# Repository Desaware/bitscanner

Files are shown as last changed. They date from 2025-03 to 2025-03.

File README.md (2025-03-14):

# Bitscanner - A LittleBits/Arduino Compatible Scope/Frequency Counter and Voltmeter - Software

Refer to https://github.com/Desaware/bitscanner/wiki for documentation.

## Software Requirements

Bitscanner is built on the Raspberry Pi Pico 1 (RP2040), using the Pico SDK under Visual Studio Code.

It also uses the pico-ssd1306 library found at https://github.com/daschr/pico-ssd1306, portions of which are included in this repository.

To build, copy the files in this directory to the root of a Raspberry Pi Pico project in VS Code. Be sure to include the CMakeList.txt file. You should then be able to compile and upload the project to your pico device when it is in bootloader mode.

Refer to your Pico documentation or friendly neighborhood AI for instructions on setting up VS Code with the Pico SDK and building and deploying software in that environment.

Disclaimer: This product is not affiliated with, endorsed by, or sponsored by Sphero, Inc. "littleBits" is a registered trademark of Sphero, Inc. All trademarks, product names, and company names or logos mentioned herein are the property of their respective owners. This device is designed to be compatible with littleBits components but is an independent creation with no official connection to Sphero, Inc.

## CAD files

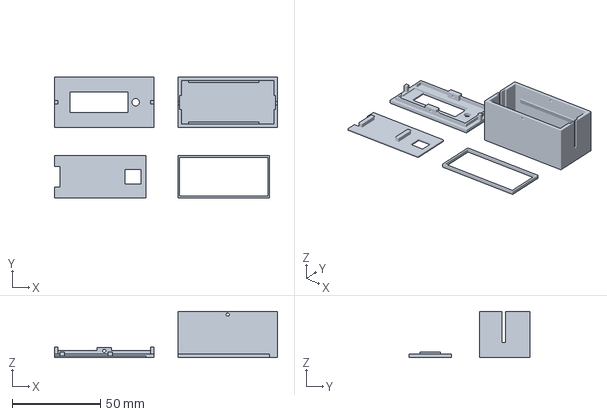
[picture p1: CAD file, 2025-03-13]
Case/sannercase.3mf
126.5 x 68.5 x 26.3 mm

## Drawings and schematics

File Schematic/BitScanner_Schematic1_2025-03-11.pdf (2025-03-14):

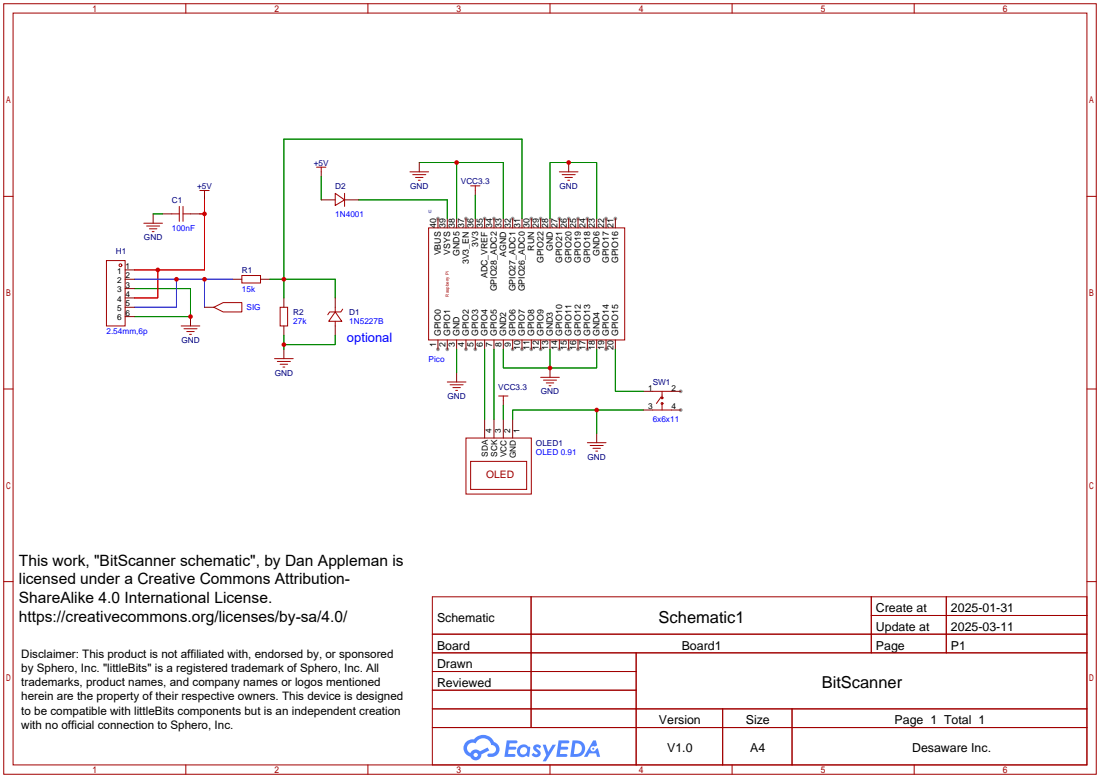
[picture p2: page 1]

This work, "BitScanner schematic", by Dan Appleman is
licensed under a Creative Commons Attribution-
ShareAlike 4.0 International License.
https://creativecommons.org/licenses/by-sa/4.0/

Schematic | Schematic1 | Create at | 2025-01-31

Update at | 2025-03-11

Board | Board1 | Page | P1
Drawn | | BitScanner
Reviewed

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

Version | Size | Page 1 Total 1
V1.0 | A4 | Desaware Inc.

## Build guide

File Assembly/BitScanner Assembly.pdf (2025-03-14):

# BitScanner Assembly

These are instructions for assembling the BitScanner using the PCB and case design provided in this repository. Obviously, you can create your own variations, in which case, just as obviously, these assembly instructions will not apply.
This document is Copyright © 2025 by Dan Appleman.
Disclaimer: This product is not affiliated with, endorsed by, or sponsored by Sphero, Inc. "LittleBits" is a trademark of Sphero, Inc. All trademarks, product names, and company names or logos mentioned herein are the property of their respective owners. This device is designed to be compatible with LittleBits components but is an independent creation with no official connection to Sphero, Inc.

## Overview

The BitScanner consists of one printed circuit board with components mounted on the top and bottom. The bottom contains the I/O connector resistors, diode and capacitor, along with 20 pin header sockets for the Raspberry Pi Pico. The pico plugs in and sits below the components (the socket, at 7mm, being tall enough to provide space for the components between the PCB and the Pico.
On the top of the PCB you have the OLED display and the push button. A spacer and display mount hold the OLED above the PCB, leaving space for the soldered connections and holding the OLED at the the correct height. A rectangular opening provides space for the button.

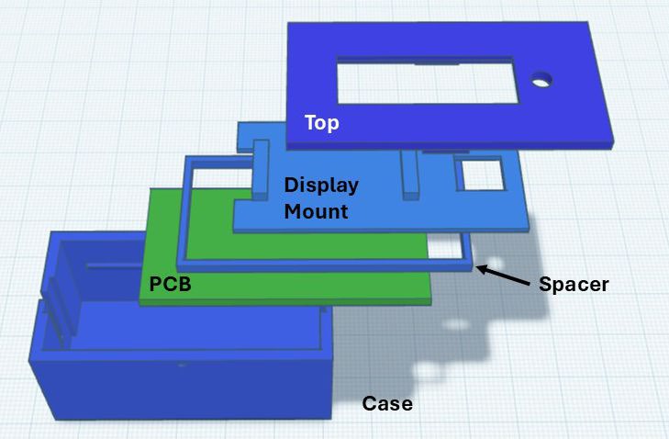
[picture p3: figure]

## PCB Bottom

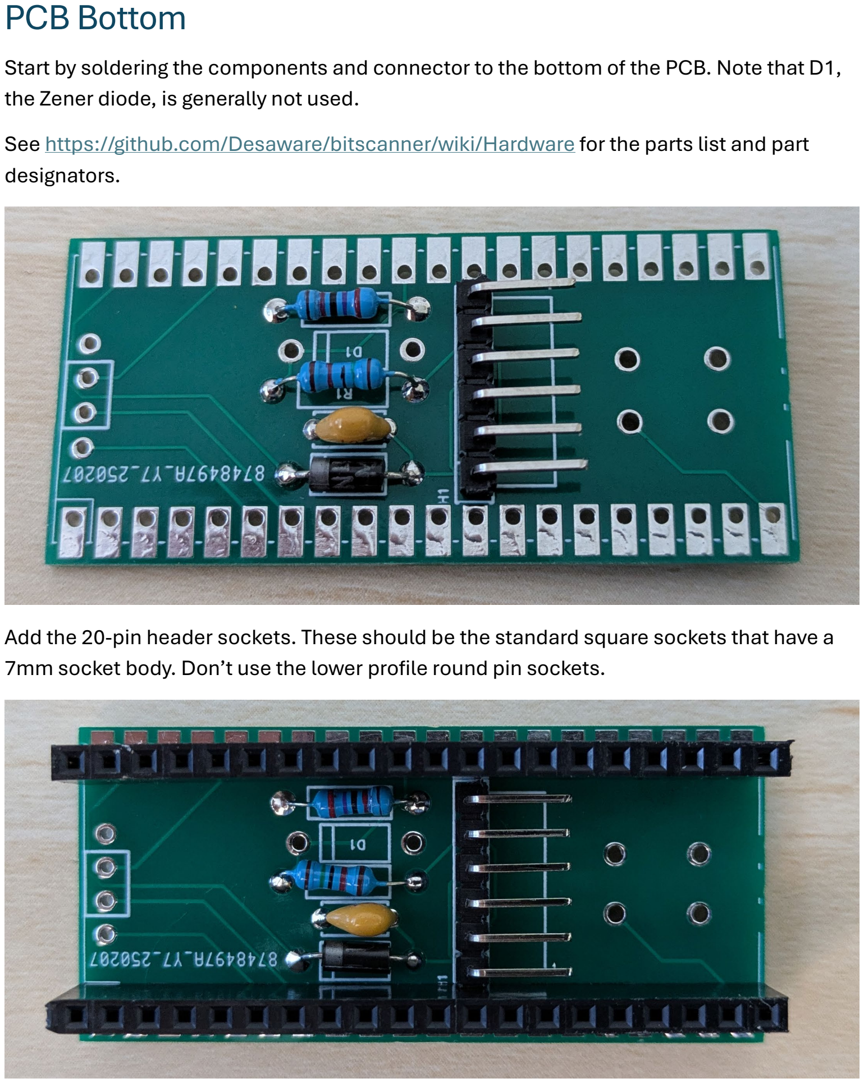
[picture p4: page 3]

Start by soldering the components and connector to the bottom of the PCB. Note that D1, the Zener diode, is generally not used.
See https://github.com/Desaware/bitscanner/wiki/Hardware for the parts list and part designators.

Add the 20-pin header sockets. These should be the standard square sockets that have a 7mm socket body. Don’t use the lower profile round pin sockets.

## PCB Top

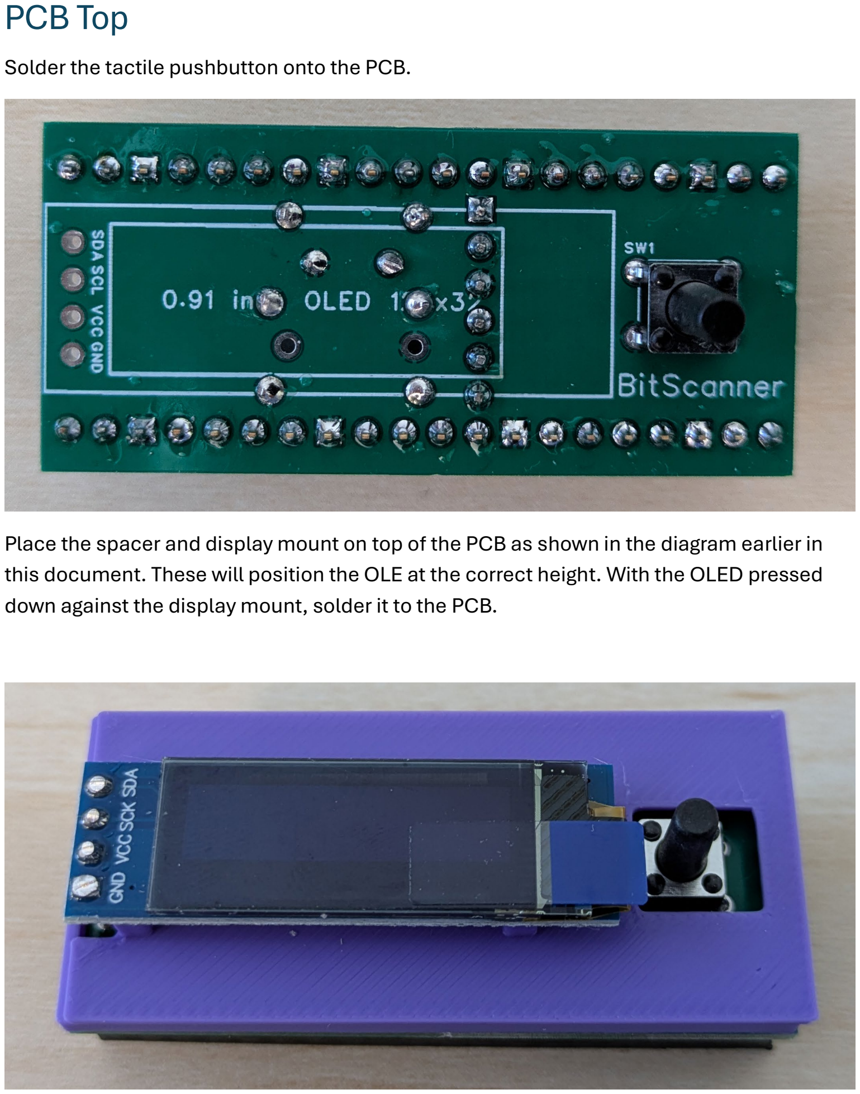
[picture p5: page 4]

Solder the tactile pushbutton onto the PCB.

Place the spacer and display mount on top of the PCB as shown in the diagram earlier in this document. These will position the OLE at the correct height. With the OLED pressed down against the display mount, solder it to the PCB.

## Wires

Connect two JST-SH wire assemblies to a 6-pin connector. On this image, pin 1 is the bottom pin on the connector.
Note the color reversal – on pins 1-3, red is +5 and ground is yellow. On pins 4-6, yellow is +5V and red is ground. This is because of the way the littleBits connectors work (+5V is always the top pin for inputs and outputs).
Plug your wire assemblies into the connectors of a littleBits W1 Wire bit. Be sure to plug the correct connector into the correct wire assembly as shown below!

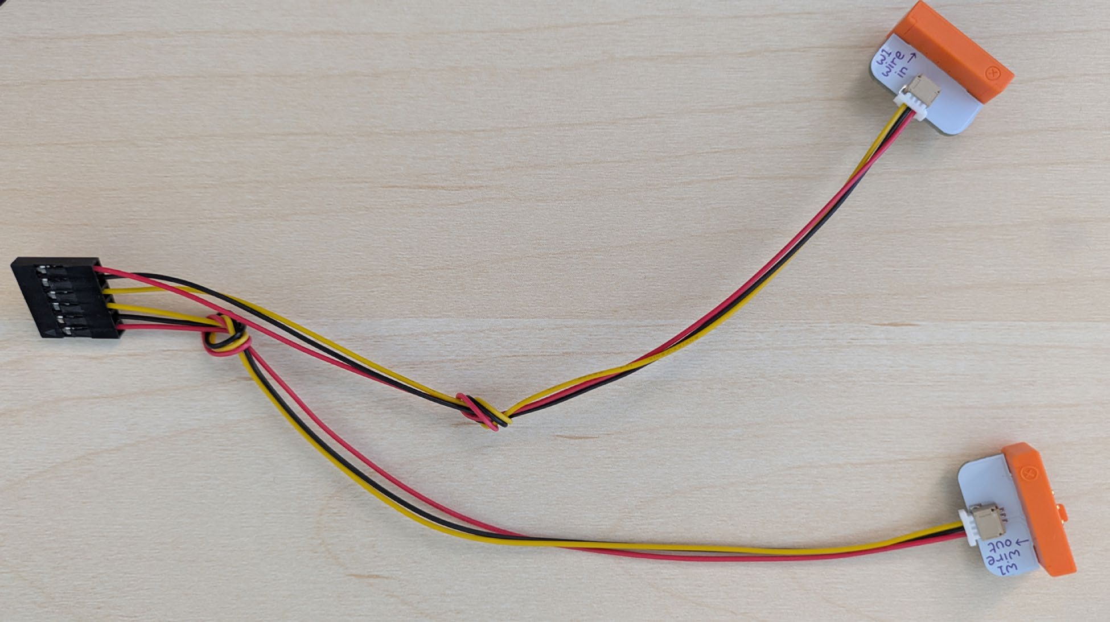
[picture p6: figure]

Tie knots in each wire as shown to act as strain reliefs.

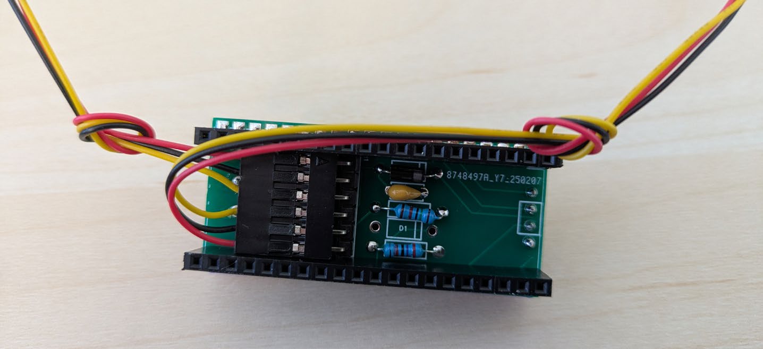
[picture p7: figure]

## Final Assembly

Plug the Raspberry Pi Pico into the header socket (be sure to program it first).
Slide the PCB assembly into the case, placing the wires in the slots. The PCB will sit on the PCB mounts in the case.
Place the case top on the case.
There are two holes on the side for #2 x ¼ self-tapping screws.

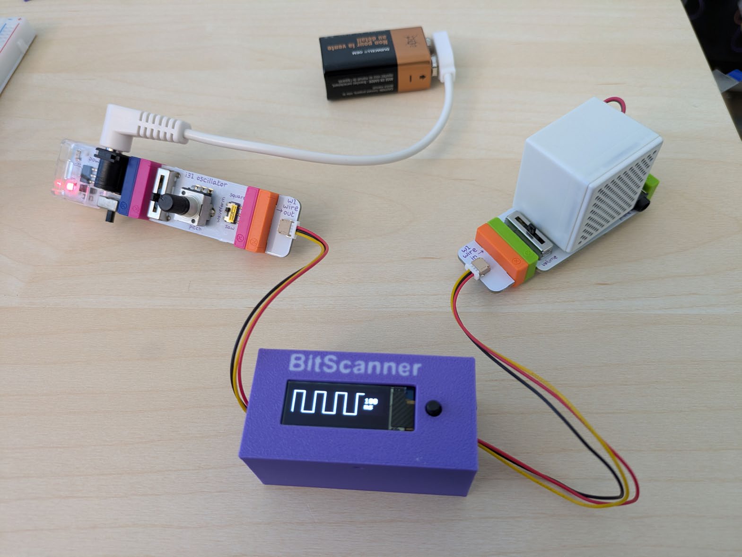
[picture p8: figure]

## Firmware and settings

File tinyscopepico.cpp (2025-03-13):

/*
    Bitscanner - a LittleBits compatible combination oscilloscope, voltmeter and frequency counter
    Copyright (C) 2025 by Dan Appleman

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
    You should have received a copy of the GNU General Public License
    along with this program.  If not, see <https://www.gnu.org/licenses/>.
*/ 

#include <stdio.h>
#include "pico/stdlib.h"
#include "hardware/i2c.h"
#include "hardware/timer.h"
#include "hardware/watchdog.h"
#include "Scope.h"

extern "C"
{
    #include "ssd1306.h"
    #include "font.h"
}

const uint LED_PIN = 25;
const uint MODE_PIN = 15;

// I2C defines
// This example will use I2C0 on GPIO8 (SDA) and GPIO9 (SCL) running at 400KHz.
// Pins can be changed, see the GPIO function select table in the datasheet for information on GPIO assignments
#define I2C_PORT i2c0
#define I2C_SDA 4
#define I2C_SCL 5

ssd1306_t disp;

int main()
{
    sleep_ms(10);  // Some setup time
    stdio_init_all();
    gpio_init(LED_PIN);
    gpio_set_dir(LED_PIN, GPIO_OUT);

    // I2C Initialisation. Using it at 400Khz.
    i2c_init(I2C_PORT, 400*1000);
    sleep_ms(10);  // Some setup time
    
    gpio_set_function(I2C_SDA, GPIO_FUNC_I2C);
    gpio_set_function(I2C_SCL, GPIO_FUNC_I2C);
    gpio_pull_up(I2C_SDA);
    gpio_pull_up(I2C_SCL);
    // For more examples of I2C use see https://github.com/raspberrypi/pico-examples/tree/master/i2c

    // Set up the mode switch
    gpio_init(MODE_PIN);
    gpio_set_dir(MODE_PIN, GPIO_IN);
    gpio_pull_up(MODE_PIN);

    // Watchdog example code
    if (watchdog_caused_reboot()) {
        printf("Rebooted by Watchdog!\n");
        // Whatever action you may take if a watchdog caused a reboot
    }
    
    // Enable the watchdog, requiring the watchdog to be updated every 100ms or the chip will reboot
    // second arg is pause on debug which means the watchdog will pause when stepping through code
    watchdog_enable(2000, 1);
    
    Scope activeScope;


 
    disp.external_vcc=false;
    ssd1306_init(&disp, 128, DISPLAYHEIGHT, 0x3C, I2C_PORT);
    ssd1306_poweron(&disp);
    ssd1306_clear(&disp);
    ssd1306_draw_string(&disp, 2, 4, 2, "BitScanner");


    ssd1306_show(&disp);

    uint64_t watchdog_time = time_us_64();
    uint64_t led_time = time_us_64();
    int ledstate = 0;

    bool debouncingMode = false;
    bool stableMode = true;
    bool lastMode = true;
    uint64_t lastModeCheck = time_us_64();



    while (true) {
        activeScope.poll();
        uint64_t current_time = time_us_64();

        /*if(current_time - led_time > 500000)
        {
            ledstate = (ledstate==0)? 1: 0;
            gpio_put(LED_PIN, ledstate);
            led_time = current_time;
            printf("Frequency: %d\n", activeScope.getCurrentFrequency());
            printf("Voltage: %f\n", activeScope.getCurrentVoltage());
        }
        */

        if(current_time - watchdog_time > 1000000)
        {
            // Once/second update the watchdog
            watchdog_update();
            watchdog_time = current_time;
        }

        bool currentMode = gpio_get(MODE_PIN);
        if(!debouncingMode)
        {
            if(currentMode != stableMode) 
            {
                debouncingMode = true;
                lastModeCheck = time_us_64();
                lastMode = currentMode;
            }
        }
        else
        {   // Debouncing
            if(currentMode != lastMode)
            {
                lastMode = currentMode;
                lastModeCheck = time_us_64();
            }
            else if (current_time - lastModeCheck > 50000)
            {
                // It's stable
                debouncingMode = false;
                stableMode = currentMode;
                if(stableMode == 0) activeScope.toggleDisplayMode();    // On button press, toggle the display
            }
        }


    }
}

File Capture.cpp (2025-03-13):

/*
    Bitscanner - a LittleBits compatible combination oscilloscope, voltmeter and frequency counter
    Copyright (C) 2025 by Dan Appleman

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
    You should have received a copy of the GNU General Public License
    along with this program.  If not, see <https://www.gnu.org/licenses/>.
*/    

#include "Capture.h"


uint16_t CapturedDataStruct::getPeakSampleValue()
{
    if(currentSample < NUM_SAMPLES) return 0;
    uint16_t startValue = (triggerLocation <0)? 0: triggerLocation;
    uint16_t maxvalue = 0;
    for(uint16_t x = startValue; x< currentSample; x++)
    {
        if(buffer[x] > maxvalue) maxvalue = buffer[x];
    }
    return maxvalue;
}


//alarm_pool_t * Capture::timerAlarmPool = NULL;
bool Capture::analogInitialized = false;

Capture::Capture(uint16_t adcChannel)
{
    m_adcChannel = adcChannel;
    if(!analogInitialized)
    {
        adc_init();
        adc_gpio_init(26);  // Enable ADC on GPIO 26     
        adc_select_input(m_adcChannel);
    }
    for(uint16_t seg = 0; seg<10; seg++) baselines[seg] = 20;    // Default baseline is 0.05 V

}

Capture::~Capture()
{
    cancel_repeating_timer(&sampling_timer);
}


bool Capture::staticTimerCallback(struct repeating_timer *t)
{
    return(((Capture *)t->user_data)->timerCallback(t));
}


uint16_t Capture::getPeakVoltage()
{
    uint16_t result = peakADCSinceLastRequest;
    peakADCSinceLastRequest = 0;
    return result;
}

uint16_t Capture::getFrequency()
{
    return currentFrequency;
}

bool Capture::timerCallback(struct repeating_timer *t)
{
    uint64_t currentTime = time_us_64();
    uint16_t currentADC = adc_read()>>2;    // We'll only use 10 bits
    // Keep track of the peak voltage since the last voltage request
    if(currentADC > peakADCSinceLastRequest) peakADCSinceLastRequest = currentADC;
    if(currentADC < lowADCforPeriod) lowADCforPeriod = currentADC;
    if(searchingForZero)
    { 
        if(currentADC < baseline){    // Below baseline (default 0.05V - allowing for rounding the lowest 10 count/ 0.05V to ground)
            searchingForZero = false;
        }
    }
    else
    {
        if(currentADC > baseline + 30)    // Must be about 0.1V above baseline (20 counts = 0.1V)
        {
            frequencyCyclesCounted++;
            searchingForZero = true;
            // First trigger when capturing
            if(captureInProgress && currentCaptureBuffer->triggerLocation<0) currentCaptureBuffer->triggerLocation = currentCaptureBuffer->currentSample;
        }
    }

    if(currentTime > tenthOfSecondSamplingEndTime)
    {
       // This logic tracks the minimum voltage over the past 10 sampling periods and considers that the baseline for frequency counting. This means it
        // can take up to a second to readjust if the lowest signal voltage rises. But it will respond quickly if the lowest voltage drops
        // We do not adjust the baselines if capturing
        uint16_t minValue = 512;    // Baseline is never above about 2.5V
        for(uint16_t seg = 0; seg<9; seg++)
        {
            if(baselines[seg] < minValue) minValue = baselines[seg];
            baselines[seg] = baselines[seg+1];
        }
        baselines[9] = lowADCforPeriod;
        baseline = minValue + 20; // Baseline is about .1 V over the lowest detected value;
        lowADCforPeriod = 512;
        tenthOfSecondSamplingEndTime = currentTime + 100000;
    }

    // Has freq sampling time passed?
    if(currentTime > frequencySamplingEndTime)
    {
        if(frequencyCyclesCounted == 0 && fullSecondSample)
        {
            currentFrequency = 0;
            fullSecondSample = false;
        }
        else if(frequencyCyclesCounted < 1000 && !fullSecondSample)
        {
            frequencySamplingEndTime = frequencySamplingEndTime + 900000;    // Extend measurement to one second
            fullSecondSample = true;
        }
        else 
        {
            currentFrequency = (fullSecondSample)? frequencyCyclesCounted: frequencyCyclesCounted * 10;
            frequencySamplingEndTime = currentTime + 100000;
            fullSecondSample = false;
            frequencyCyclesCounted = 0;
        }
    }
    if(!captureInProgress || !currentCaptureBuffer) return true; // No capturing or buffer not defined
    currentDividerCount-=1;
    if(currentDividerCount > 0) return true;
    currentDividerCount = currentCaptureBuffer->divisor;
    if(currentCaptureBuffer->currentSample < sizeof(currentCaptureBuffer->buffer))
    {
        currentCaptureBuffer->buffer[currentCaptureBuffer->currentSample++] = currentADC;
        if( (currentCaptureBuffer->triggerLocation>=0 && (currentCaptureBuffer->currentSample - currentCaptureBuffer->triggerLocation) > NUM_SAMPLES+1) ||
            (currentCaptureBuffer->triggerLocation==-1 && currentCaptureBuffer->currentSample >= NUM_SAMPLES) )
        {
            // We have NUM_SAMPLES valid samples past the trigger, we're done
            // Or we've captured NUM_SAMPLES DC (trigger not found)
            captureInProgress = false;
            currentCaptureBuffer->endFrequency = currentFrequency;
            currentCaptureBuffer->captureComplete = true;
            return true;
        }
        return true;    // On to next cycle
    }
    // This shouldn't ever happen, but just in case, let's not overflow the buffer.
    captureInProgress = false;
    currentCaptureBuffer->endFrequency = currentFrequency;
    currentCaptureBuffer->captureComplete = true;
    return true;
}

// Call with NULL parameter to initially start the timer
bool Capture::startCapture(CapturedDataStruct *cds)
{
    if(captureInProgress) return false;
    currentCaptureBuffer = cds;
    if(cds != NULL)
    {
        currentDividerCount = cds->divisor;
        cds->currentSample = 0;
        cds->triggerLocation = -1;
        captureInProgress = true;
    }
    if(!timerOn)
    {
        timerOn = true;
        //memset(&sampling_timer, 0, sizeof(sampling_timer)); // Clear the existing structure
        if (!  add_repeating_timer_us(-SAMPLE_RATE_US, staticTimerCallback, this, &sampling_timer)) {
            printf("Failed to start ADC sampling timer!");
            captureInProgress = false;
            return false;
        }
        frequencySamplingStartTime = time_us_64();
        frequencyCyclesCounted = 0;
        frequencySamplingEndTime = 100000;  // 100ms default sampling time
        tenthOfSecondSamplingEndTime = 100000;  // 100ms 1/10 second sampling time
    }
    
    return true;

}

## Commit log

2025-03-13 Initial V1 release commit
    [sannercase.3mf]
2025-03-14 Disclaimers and assembly instructions.

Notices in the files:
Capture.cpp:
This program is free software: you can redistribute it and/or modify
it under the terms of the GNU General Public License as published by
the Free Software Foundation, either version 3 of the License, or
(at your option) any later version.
